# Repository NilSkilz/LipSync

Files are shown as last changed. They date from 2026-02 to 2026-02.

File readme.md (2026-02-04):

# LipSync

A rhythm-guided training system with haptic feedback. Turn oral service into a game they *really* don't want to lose.

Your sub follows a wave pattern on their phone while wearing an RF shock collar. Fall out of rhythm? They get a reminder. You control the pace.

Everything runs on a single ESP32 - no cloud, no apps to install, completely self-contained.

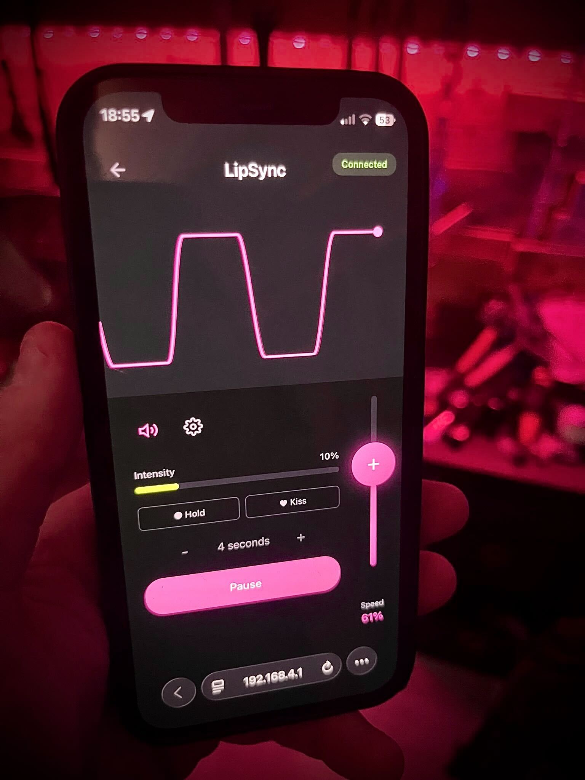
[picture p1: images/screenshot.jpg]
LipSync Screenshot


## Features

- **Visual guidance** - Smooth wave pattern shows the target rhythm
- **Audio cues** - High/low beeps signal direction changes
- **Adjustable pace** - Slide to control speed in real-time
- **Escalating feedback** - Starts gentle, increases with repeated mistakes
- **Shock collar integration** - Works with cheap 433MHz RF collars
- **Hold modes** - Special modes for deepthroat and kiss/lick
- **Motion tracking** - Optional IMU shows their actual movement vs target
- **No internet required** - Works completely offline
- **Mobile-first UI** - Designed for phones and tablets
- **Deep sleep** - Automatically sleeps after 1 minute of inactivity to save battery

## How It Works

```
┌──────────────────┐         ┌──────────────────────────────────┐
│   Phone/Tablet   │         │         ESP32 Device             │
│    (Browser)     │◄───────►│                                  │
│                  │  WiFi   │  - Web server (serves React app) │
│  Opens:          │         │  - WebSocket (real-time comms)   │
│  lipsync.local   │         │  - RF transmitter (collar ctrl)  │
│                  │         │  - MPU6050 IMU (motion tracking) │
└──────────────────┘         └──────────────────────────────────┘
```

The ESP32 creates its own WiFi network. Connect your phone, open the browser, and you're ready to play.

## Bill of Materials

| Component | Description | Qty | Approx. Price | Notes |
|---|---|-----|---|---|
| Seeed XIAO ESP32C3 | Compact ESP32-C3 board | 1 | $5-10 | Built-in LiPo charging |
| 3.7V LiPo Battery | 400-1000mAh | 1 | $5-10 | Connects to BAT+/BAT- pads |
| 433MHz RF Transmitter | FS1000A or similar | 1 | $2-5 | For collar control |
| RF Shock Collar | CaiXianlin protocol (common on Amazon/AliExpress) | 1 | $20-40 | The cheap ones with 3 channels |
| MPU6050 IMU | GY-521 module | 1 | $2-5 | Optional - for motion tracking |
| Tactile Button | 6x6mm momentary switch | 1 | $1 | Reset/wake button |
| LEDs | 3mm or 5mm, any color | 2 | $1 | Status indicators |
| Resistors | 220Ω (1/4W) | 2 | $1 | For LEDs |
| Enclosure | 3D printed or project box | 1 | $5 | Optional - STL files included |

**Total cost: ~$40-80** (depending on what you already have)

### Where to Buy

- **XIAO ESP32C3**: [Seeed Studio](https://www.seeedstudio.com/Seeed-XIAO-ESP32C3-p-5431.html), Amazon, AliExpress
- **RF Transmitter**: Search "433MHz transmitter module FS1000A"
- **Shock Collar**: Search "dog training collar 433MHz" - look for ones with vibrate/beep/shock modes
- **MPU6050**: Search "MPU6050 GY-521 module"
- **LiPo Battery**: Any 3.7V LiPo with JST connector (400-1000mAh recommended)

## Wiring

```
XIAO Pin      Component
──────────    ─────────
D10 (GPIO10)  RF Transmitter DATA
D4 (GPIO6)    MPU6050 SDA (optional)
D5 (GPIO7)    MPU6050 SCL (optional)
D0 (GPIO2)    Green LED → 220Ω → GND (connection status)
D3 (GPIO5)    Red LED → 220Ω → GND (session status)
D1 (GPIO3)    Button → GND (reset/wake, hold 1s)
3.3V          RF Transmitter VCC, MPU6050 VCC
GND           RF Transmitter GND, MPU6050 GND
BAT+/BAT-     3.7V LiPo battery
```

**Note**: RF range is reduced at 3.3V but sufficient for close range use. The XIAO charges the LiPo via USB-C.

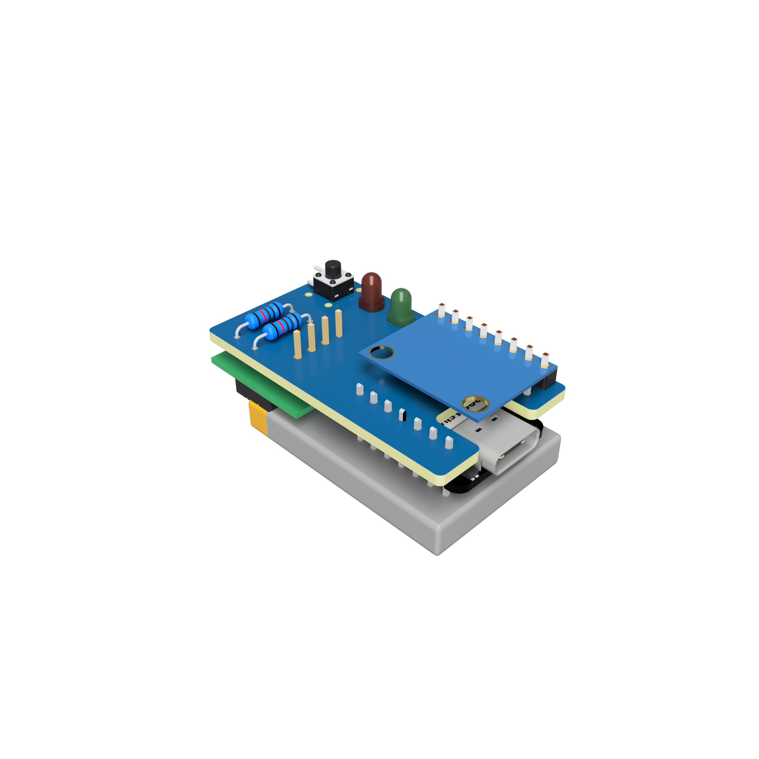
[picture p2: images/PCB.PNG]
LipSync PCB

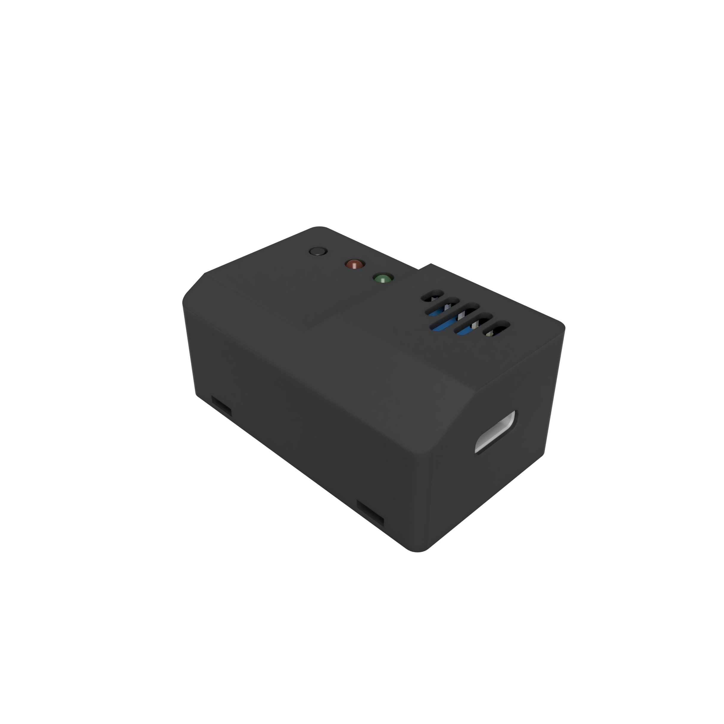
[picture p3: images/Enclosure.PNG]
LipSync Enclosure


## Quick Start

### 1. Flash the Firmware

```bash
# Install PlatformIO
brew install platformio   # macOS
# or: pip install platformio

# Clone and build
git clone https://github.com/yourusername/lipsync.git
cd lipsync/client
npm install
npm run build
cp -r dist/* ../firmware/data/

# Upload to XIAO ESP32C3
cd ../firmware
pio run -t upload -e seeed_xiao_esp32c3      # Upload firmware
pio run -t uploadfs -e seeed_xiao_esp32c3    # Upload web files
pio device monitor -b 115200                  # Monitor serial output
```

### 2. Connect and Play

1. Power on the ESP32
2. Connect to the "LipSync" WiFi network (password: `lipsync123`)
3. Open `http://lipsync.local` in your browser (or `http://192.168.4.1`)
4. Tap "Play" to begin!

### 3. Pairing the collar

Collars can be put into pairing mode by pressing the power button for ~2 seconds. There will be a beep, and the light will flash continuously.
To pair, send a "beep" signal from the app (open the settings cog and click the "Beep" button)

## Usage

### Main Controls

- **Speed Slider** (right side) - Drag up/down to control pace
- **Start/Pause** - Begin or pause the session
- **Hold/Kiss** - Quick buttons for hold modes

### Settings (gear icon)

- **Punishment Mode**: Beep, Vibrate, or Shock
- **Max Intensity**: Limit for shock strength
- **Increasing Intensity**: Start low, escalate with mistakes

### How Feedback Works

1. **Grace period** after speed changes - time to adjust
2. **First mistake** at a given speed - warning vibration
3. **Repeated mistakes** - shock at current intensity
4. **Each punishment** - intensity increases (if enabled)
5. **Speed change** - resets warning, gives grace period

## Development

### Local Web Development

```bash
cd client
npm run dev    # Starts at http://localhost:5173
```

### Firmware Development

```bash
cd firmware
pio run -e seeed_xiao_esp32c3                 # Build
pio run -t upload -e seeed_xiao_esp32c3       # Upload firmware
pio run -t uploadfs -e seeed_xiao_esp32c3     # Upload web files
pio device monitor -b 115200                   # Serial monitor
```

### Serial Commands

Connect at 115200 baud for debugging:
- `v` - Test vibrate
- `b` - Test beep
- `s` - Show status
- `h` - Help

## Project Structure

```
lipsync/
├── client/                 # React web app (Vite + TypeScript)
│   ├── src/
│   │   ├── components/     # UI components
│   │   ├── context/        # State management
│   │   ├── hooks/          # useWebSocket, useAudio
│   │   └── styles/         # CSS
│   └── package.json
├── firmware/               # ESP32 firmware (PlatformIO)
│   ├── src/main.cpp        # Main firmware
│   ├── include/            # Headers (config, RF, IMU)
│   ├── data/               # Built web files (LittleFS)
│   └── platformio.ini
├── enclosure/              # 3D printable enclosure STLs
└── screenshots/
```

## Power Management

The device automatically enters deep sleep after 1 minute of inactivity (no connected client and no active session) to conserve battery. Press the button to wake it up - LEDs will blink 3 times on boot.

Activity that resets the idle timer:
- Button press
- WebSocket client connecting
- WebSocket messages received
- Motion detected (cycles)

## Troubleshooting

### Can't connect to WiFi
- Make sure you're connecting to "LipSync" network
- Password is `lipsync123`
- Try `http://192.168.4.1` if `.local` doesn't work

### Collar not responding
- Check RF transmitter wiring (DATA to D10/GPIO10)
- Use serial monitor to confirm signals are being sent
- Ensure collar is paired (see pairing instructions above)

### Upload fails
- Try a different USB cable (must be data, not charge-only)
- Close any serial monitors first
- Make sure you're using `-e seeed_xiao_esp32c3`

### Web app not loading
- Make sure filesystem was uploaded: `pio run -t uploadfs -e seeed_xiao_esp32c3`
- Check serial output for errors

## Safety

This project involves shock collars. Please:
- **Always have a safeword** and a way to immediately stop
- **Test intensity on yourself first** before using on a partner
- **Start at low intensity** and increase gradually
- **Never use on anyone with a heart condition** or pacemaker
- **Remove if any unusual reaction occurs**
- This is for **consensual adult play only**

## Contributing

PRs welcome! Some ideas for improvements:
- [ ] Bluetooth collar support
- [ ] Pattern presets (slow build, random, etc.)
- [ ] Multi-sub support
- [ ] Session statistics/scoring
- [ ] OTA firmware updates

## License

MIT License - do whatever you want with it.

## Acknowledgments

- Built with [PlatformIO](https://platformio.org/), [React](https://react.dev/), [Vite](https://vitejs.dev/)
- RF protocol reverse-engineered from CaiXianlin collar remotes
- Massive props to Openshock for their work with the RF collars
- Thanks to some random guy off reddit for the idea
- Inspired by too many late nights and questionable life choices

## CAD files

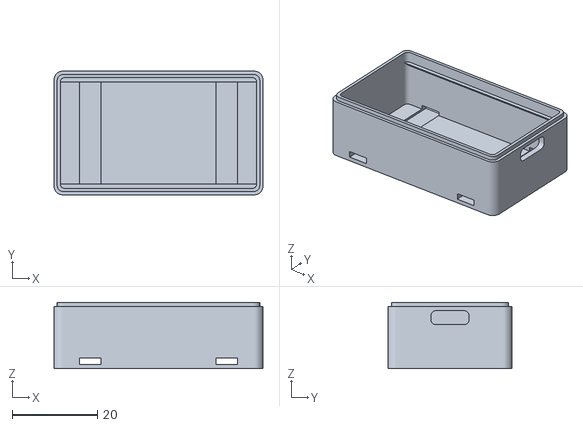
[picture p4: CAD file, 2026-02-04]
enclosure/Lower Body.stl
49.0 x 29.0 x 15.5

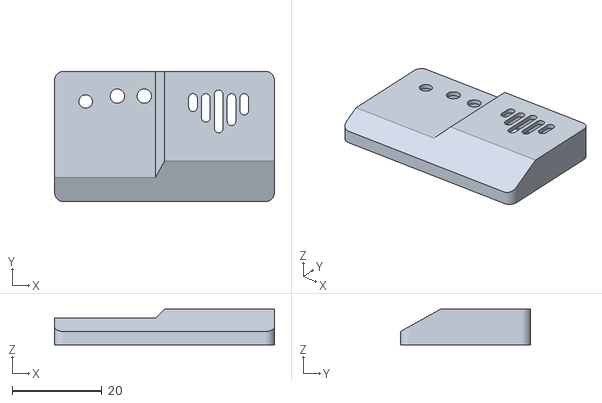
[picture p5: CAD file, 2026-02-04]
enclosure/Upper Body.stl
49.0 x 29.0 x 8.00

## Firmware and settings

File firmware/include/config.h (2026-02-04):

#pragma once

// ============================================
// PIN CONFIGURATION (XIAO ESP32C3)
// ============================================

// RF Transmitter pin (433MHz FS1000A)
#ifndef RF_TX_PIN
#define RF_TX_PIN 10  // D10
#endif

// IMU I2C pins (MPU6050/GY-521)
#ifndef IMU_SDA_PIN
#define IMU_SDA_PIN 6  // D4
#endif

#ifndef IMU_SCL_PIN
#define IMU_SCL_PIN 7  // D5
#endif

// Status LEDs
#ifndef LED_PIN
#define LED_PIN 2  // D0 - Green (connection status)
#endif

#ifndef LED2_PIN
#define LED2_PIN 5  // D3 - Red (session status)
#endif

// Button (active-low, uses internal pull-up)
#ifndef BUTTON_PIN
#define BUTTON_PIN 3  // D1
#endif

// ============================================
// WEBSOCKET SERVER CONFIGURATION
// ============================================

// mDNS hostname (device will be accessible at lipsync.local)
#define MDNS_HOSTNAME "lipsync"

// WebSocket server port
#define WS_PORT 80

// ============================================
// SHOCKER CONFIGURATION
// ============================================

// CaiXianlin protocol
#define SHOCKER_TRANSMITTER_ID 12345  // Change this! Must match your paired collar
#define SHOCKER_CHANNEL 0             // 0, 1, or 2

// ============================================
// MOTION DETECTION
// ============================================

// IMU sample rate (Hz)
#define IMU_SAMPLE_RATE 50

// Enable pitch streaming for visualization (comment out to disable)
// #define ENABLE_PITCH_STREAMING

// Minimum angle change to detect a peak (degrees)
#define PEAK_THRESHOLD 3.0

// Minimum cycle time (ms) - prevents noise
#define MIN_CYCLE_TIME 200

// Maximum cycle time (ms) - prevents stale readings
#define MAX_CYCLE_TIME 5000

// ============================================
// FEEDBACK DEFAULTS
// ============================================

#define DEFAULT_TARGET_BPM 60
#define DEFAULT_TARGET_DEPTH 30
#define DEFAULT_TOLERANCE 0.3
#define DEFAULT_INTENSITY 50

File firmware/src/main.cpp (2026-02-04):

#include <Arduino.h>
#include <WiFi.h>
#include <ESPmDNS.h>
#include <LittleFS.h>
#include <ESPAsyncWebServer.h>
#include <ArduinoJson.h>
#include "config.h"
#include "rf_transmitter.h"
#include "motion_tracker.h"
#include "esp_sleep.h"

// Components
RFTransmitter rf(RF_TX_PIN);
MotionTracker motion;
AsyncWebServer server(WS_PORT);
AsyncWebSocket ws("/ws");

// Hardware status
bool rfAvailable = false;
bool imuAvailable = false;

// Deep sleep
const unsigned long IDLE_SLEEP_TIMEOUT = 1 * 60 * 1000; // 1 minute idle timeout
unsigned long lastActivityTime = 0;

// Punishment modes
enum PunishmentMode { PUNISHMENT_OFF = 0, PUNISHMENT_BEEP = 1, PUNISHMENT_VIBRATE = 2, PUNISHMENT_SHOCK = 3 };

// Session modes (normal = motion tracking, others = hold positions)
enum SessionMode { MODE_NORMAL = 0, MODE_KISS_LICK = 1, MODE_DEEPTHROAT = 2 };

// Session state
struct SessionConfig {
    bool active = false;
    int targetBPM = DEFAULT_TARGET_BPM;
    int targetDepth = DEFAULT_TARGET_DEPTH;
    float tolerance = DEFAULT_TOLERANCE;
    int intensity = DEFAULT_INTENSITY;
    int maxIntensity = DEFAULT_INTENSITY;  // Maximum intensity cap
    bool increasingIntensity = true;       // Start low and increase
    int currentIntensity = 10;             // Current level (when increasing)
    uint16_t transmitterId = SHOCKER_TRANSMITTER_ID;
    uint8_t channel = SHOCKER_CHANNEL;
    int graceCycles = 0;  // Cycles to skip feedback after target change
    PunishmentMode punishmentMode = PUNISHMENT_VIBRATE;
    bool shockWarningGiven = false;  // For shock mode: one warning per speed
    SessionMode sessionMode = MODE_NORMAL;  // Current session mode
} session;

const int INTENSITY_START = 10;      // Starting intensity when increasing
const int INTENSITY_INCREMENT = 5;   // How much to increase each time

const int GRACE_PERIOD_CYCLES = 3;

// Connected client (we only support one at a time)
AsyncWebSocketClient* connectedClient = nullptr;

// Timing
unsigned long lastSample = 0;
unsigned long lastBlink = 0;
unsigned long lastCycleTime = 0;
unsigned long lastPitchBroadcast = 0;
unsigned long buttonPressStart = 0;
const unsigned long SAMPLE_INTERVAL = 1000 / IMU_SAMPLE_RATE;
const unsigned long BLINK_INTERVAL = 1000;
const unsigned long PITCH_BROADCAST_INTERVAL = 20;  // Send pitch every 20ms (50Hz, matches IMU)
const int STALL_CYCLE_COUNT = 3;  // Feedback after this many missed cycles
const unsigned long BUTTON_HOLD_TIME = 1000;  // Hold button 1 second to reset

// Forward declarations
void handleWebSocketMessage(void* arg, uint8_t* data, size_t len);
void onWsEvent(AsyncWebSocket* server, AsyncWebSocketClient* client, AwsEventType type, void* arg, uint8_t* data, size_t len);
void evaluateAndFeedback(const CycleEvent& cycle);
void broadcastState();
void sendToClient(const String& json);

// List directory recursively
void listDir(fs::FS &fs, const char* dirname, uint8_t levels) {
    Serial.printf("Listing directory: %s\n", dirname);
    File root = fs.open(dirname);
    if (!root || !root.isDirectory()) {
        Serial.println("  Failed to open directory");
        return;
    }
    File file = root.openNextFile();
    while (file) {
        if (file.isDirectory()) {
            Serial.printf("  DIR: %s\n", file.path());
            if (levels) {
                listDir(fs, file.path(), levels - 1);
            }
        } else {
            Serial.printf("  FILE: %s (%d bytes)\n", file.path(), file.size());
        }
        file = root.openNextFile();
    }
}

void enterDeepSleep() {
    Serial.println("Entering deep sleep...");

    // Turn off LEDs
    digitalWrite(LED_PIN, LOW);
    digitalWrite(LED2_PIN, LOW);

    // Stop services cleanly
    WiFi.mode(WIFI_OFF);
    btStop();

    // Wake on button press (D1 = GPIO3, active LOW)
    esp_deep_sleep_enable_gpio_wakeup(
        BIT(GPIO_NUM_3),
        ESP_GPIO_WAKEUP_GPIO_LOW
    );

    delay(100); // Let serial flush
    esp_deep_sleep_start();
}

void setup() {
    Serial.begin(115200);
    delay(1000);
    Serial.println("\n\n=== LipSync Firmware ===");

    esp_sleep_wakeup_cause_t wakeReason = esp_sleep_get_wakeup_cause();
    if (wakeReason == ESP_SLEEP_WAKEUP_GPIO) {
        Serial.println("Woke from deep sleep via button");
    } else {
        Serial.println("Normal boot");
    }

    // Status LEDs
    pinMode(LED_PIN, OUTPUT);   // LED1: Green - Connection status
    pinMode(LED2_PIN, OUTPUT);  // LED2: Red - Session status

    // Blink LEDs on boot to verify wiring
    Serial.println("LED test...");
    for (int i = 0; i < 3; i++) {
        digitalWrite(LED_PIN, HIGH);
        digitalWrite(LED2_PIN, HIGH);
        delay(150);
        digitalWrite(LED_PIN, LOW);
        digitalWrite(LED2_PIN, LOW);
        delay(150);
    }

    // Reset button (active-low with internal pull-up)
    pinMode(BUTTON_PIN, INPUT_PULLUP);

    // Initialize LittleFS
    if (!LittleFS.begin(true)) {
        Serial.println("LittleFS mount failed!");
    } else {
        Serial.println("LittleFS mounted");
        // List all files recursively
        listDir(LittleFS, "/", 3);
    }

    // Initialize RF transmitter (optional)
    rfAvailable = rf.begin();
    if (!rfAvailable) {
        Serial.println("RF init failed - continuing without RF");
    }

    // Initialize motion tracker (optional)
    imuAvailable = motion.begin();
    if (!imuAvailable) {
        Serial.println("IMU init failed - continuing without IMU");
    }

    // Start Access Point
    WiFi.mode(WIFI_AP);
    const char* apSSID = "LipSync";
    const char* apPassword = "lipsync123";  // Min 8 characters
    WiFi.softAP(apSSID, apPassword);
    Serial.printf("Access Point started: %s (password: %s)\n", apSSID, apPassword);
    Serial.printf("AP IP Address: %s\n", WiFi.softAPIP().toString().c_str());

    // Start mDNS
    if (MDNS.begin(MDNS_HOSTNAME)) {
        Serial.printf("mDNS started: http://%s.local\n", MDNS_HOSTNAME);
        MDNS.addService("http", "tcp", WS_PORT);
    } else {
        Serial.println("mDNS failed to start");
    }

    // Setup WebSocket handler
    ws.onEvent(onWsEvent);
    server.addHandler(&ws);

    // Serve static files from LittleFS with correct MIME types
    server.on("/assets/index.js", HTTP_GET, [](AsyncWebServerRequest* request) {
        Serial.println("Request for /assets/index.js");
        if (LittleFS.exists("/assets/index.js")) {
            Serial.println("  File exists!");
            request->send(LittleFS, "/assets/index.js", "application/javascript");
        } else {
            Serial.println("  File NOT found!");
            request->send(404, "text/plain", "File not found");
        }
    });
    server.on("/assets/index.css", HTTP_GET, [](AsyncWebServerRequest* request) {
        Serial.println("Request for /assets/index.css");
        if (LittleFS.exists("/assets/index.css")) {
            Serial.println("  File exists!");
            request->send(LittleFS, "/assets/index.css", "text/css");
        } else {
            Serial.println("  File NOT found!");
            request->send(404, "text/plain", "File not found");
        }
    });
    server.on("/assets/audio/kiss-lick.mp3", HTTP_GET, [](AsyncWebServerRequest* request) {
        Serial.println("Request for /assets/audio/kiss-lick.mp3");
        if (LittleFS.exists("/assets/audio/kiss-lick.mp3")) {
            Serial.println("  File exists!");
            request->send(LittleFS, "/assets/audio/kiss-lick.mp3", "audio/mpeg");
        } else {
            Serial.println("  File NOT found!");
            request->send(404, "text/plain", "File not found");
        }
    });

    // Serve other static files
    server.serveStatic("/", LittleFS, "/").setDefaultFile("index.html");

    // Handle 404 - serve index.html for SPA routing
    server.onNotFound([](AsyncWebServerRequest* request) {
        Serial.printf("404: %s\n", request->url().c_str());
        if (LittleFS.exists("/index.html")) {
            request->send(LittleFS, "/index.html", "text/html");
        } else {
            request->send(404, "text/plain", "Not found - upload filesystem first");
        }
    });

    // Start server
    server.begin();
    Serial.printf("Web server started on port %d\n", WS_PORT);

    digitalWrite(LED_PIN, LOW);
    Serial.println("Setup complete!");
    Serial.printf("Open: http://%s.local or http://%s\n",
                  MDNS_HOSTNAME,
                  WiFi.softAPIP().toString().c_str());
    lastActivityTime = millis();
}

void loop() {
    unsigned long now = millis();
    // Check reset button (hold for 1 second to reset)
    if (digitalRead(BUTTON_PIN) == LOW) {
        lastActivityTime = now;
        if (buttonPressStart == 0) {
            buttonPressStart = millis();
            Serial.println("Button pressed - hold 1s to reset");
        } else if (millis() - buttonPressStart >= BUTTON_HOLD_TIME) {
            Serial.println("Resetting...");
            delay(100);
            ESP.restart();
        }
    } else {
        buttonPressStart = 0;
    }

    // LED1: Blink - fast when client connected, slow when waiting
    unsigned long blinkRate = connectedClient ? 200 : 1000;
    if (millis() - lastBlink >= blinkRate) {
        lastBlink = millis();
        digitalWrite(LED_PIN, !digitalRead(LED_PIN));
    }

    // LED2: Solid when session active
    digitalWrite(LED2_PIN, session.active ? HIGH : LOW);

    // Handle serial commands for testing
    if (Serial.available()) {
        String cmd = Serial.readStringUntil('\n');
        cmd.trim();
        if (cmd == "v" || cmd == "vibrate") {
            Serial.println("Vibrate command (50%)");
            if (rfAvailable) {
                rf.vibrate(session.transmitterId, session.channel, 50);
            } else {
                Serial.println("(RF not available)");
            }
        } else if (cmd == "b" || cmd == "beep") {
            Serial.println("Beep command");
            if (rfAvailable) {
                rf.beep(session.transmitterId, session.channel);
            } else {
                Serial.println("(RF not available)");
            }
        } else if (cmd == "s" || cmd == "status") {
            Serial.printf("RF: %s, IMU: %s, Client: %s\n",
                rfAvailable ? "OK" : "NO",
                imuAvailable ? "OK" : "NO",
                connectedClient ? "CONNECTED" : "NONE");
            Serial.printf("IP: %s\n", WiFi.localIP().toString().c_str());
            Serial.printf("Transmitter ID: %d, Channel: %d\n", session.transmitterId, session.channel);
        } else if (cmd == "r" || cmd == "reset") {
            Serial.println("Resetting...");
            delay(100);
            ESP.restart();
        } else if (cmd == "h" || cmd == "help") {
            Serial.println("Commands: v=vibrate, b=beep, s=status, r=reset, h=help");
        } else if (cmd.length() > 0) {
            Serial.println("Unknown command. Type 'h' for help.");
        }
    }

    // Clean up disconnected WebSocket clients
    ws.cleanupClients();

    // Sample IMU at fixed rate (only if available)
    if (imuAvailable && millis() - lastSample >= SAMPLE_INTERVAL) {
        lastSample = millis();

        motion.update();

        // Check for completed cycle
        if (motion.hasCycle()) {
            lastActivityTime = now;
            CycleEvent cycle = motion.getCycle();
            lastCycleTime = millis();

            if (session.active) {
                evaluateAndFeedback(cycle);
            }

            // Send cycle data to client
            if (connectedClient) {
                JsonDocument doc;
                doc["type"] = "cycle";
                doc["data"]["duration"] = cycle.duration;
                doc["data"]["depth"] = cycle.depth;
                doc["data"]["timestamp"] = cycle.timestamp;

                String json;
                serializeJson(doc, json);
                sendToClient(json);
            }
        }

        #ifdef ENABLE_PITCH_STREAMING
        // Broadcast pitch at throttled rate for visualization (25Hz)
        if (connectedClient && millis() - lastPitchBroadcast >= 40) {
            lastPitchBroadcast = millis();
            JsonDocument doc;
            doc["type"] = "pitch";
            doc["data"]["pitch"] = motion.getPitch();
            String json;
            serializeJson(doc, json);
            sendToClient(json);
        }
        #endif

        // Check for stall (no motion for too long) - only in normal mode
        if (session.active && session.sessionMode == MODE_NORMAL && session.graceCycles == 0 && lastCycleTime > 0) {
            unsigned long expectedCycleTime = 60000 / session.targetBPM;
            unsigned long stallTimeout = expectedCycleTime * STALL_CYCLE_COUNT;
            unsigned long timeSinceLastCycle = millis() - lastCycleTime;

            if (timeSinceLastCycle > stallTimeout && session.punishmentMode != PUNISHMENT_OFF) {
                Serial.printf("STALL detected: no motion for %lums (timeout: %lums)\n",
                              timeSinceLastCycle, stallTimeout);

                // Calculate feedback intensity
                int feedbackIntensity;
                if (session.increasingIntensity) {
                    feedbackIntensity = session.currentIntensity;
                } else {
                    feedbackIntensity = session.maxIntensity;
                }

                const char* punishmentType = "none";
                bool isWarning = false;

                if (rfAvailable) {
                    switch (session.punishmentMode) {
                        case PUNISHMENT_BEEP:
                            rf.beep(session.transmitterId, session.channel);
                            punishmentType = "beep";
                            break;
                        case PUNISHMENT_VIBRATE:
                            rf.vibrate(session.transmitterId, session.channel, feedbackIntensity);
                            punishmentType = "vibrate";
                            break;
                        case PUNISHMENT_SHOCK:
                            // One warning per speed, then shock
                            if (!session.shockWarningGiven) {
                                rf.vibrate(session.transmitterId, session.channel, feedbackIntensity);
                                punishmentType = "vibrate";
                                isWarning = true;
                                session.shockWarningGiven = true;
                                // Grace period after warning to correct
                                session.graceCycles = GRACE_PERIOD_CYCLES;
                            } else {
                                rf.shock(session.transmitterId, session.channel, feedbackIntensity);
                                punishmentType = "shock";
                                // Grace period after shock to recover
                                session.graceCycles = GRACE_PERIOD_CYCLES;
                            }
                            break;
                        default:
                            break;
                    }
                }

                // Increase intensity for next time (if enabled), but not for warnings
                if (session.increasingIntensity && !isWarning) {
                    session.currentIntensity = min(session.currentIntensity + INTENSITY_INCREMENT, session.maxIntensity);
                    Serial.printf("Next intensity: %d%% (max: %d%%)\n", session.currentIntensity, session.maxIntensity);
                }

                // Reset timer to avoid continuous feedback
                lastCycleTime = millis();

                // Notify client
                if (connectedClient) {
                    JsonDocument doc;
                    doc["type"] = "punishment";
                    doc["data"]["punishmentType"] = punishmentType;
                    doc["data"]["intensity"] = feedbackIntensity;
                    doc["data"]["isWarning"] = isWarning;
                    doc["data"]["reason"] = "stall";
                    String json;
                    serializeJson(doc, json);
                    sendToClient(json);
                }
            }
        }
    }
    if (!session.active &&
        !connectedClient &&
        (now - lastActivityTime > IDLE_SLEEP_TIMEOUT)) {

        Serial.println("Idle timeout reached");
        delay(200);
        enterDeepSleep();
    }
}

void onWsEvent(AsyncWebSocket* server, AsyncWebSocketClient* client, AwsEventType type, void* arg, uint8_t* data, size_t len) {
    switch (type) {
        case WS_EVT_CONNECT:
            lastActivityTime = millis();
            Serial.printf("WebSocket client #%u connected from %s\n", client->id(), client->remoteIP().toString().c_str());
            connectedClient = client;
            broadcastState();
            break;

        case WS_EVT_DISCONNECT:
            Serial.printf("WebSocket client #%u disconnected\n", client->id());
            if (connectedClient == client) {
                connectedClient = nullptr;
                session.active = false;  // Safety: stop session on disconnect
            }
            break;

        case WS_EVT_DATA:
            lastActivityTime = millis();
            handleWebSocketMessage(arg, data, len);
            break;

        case WS_EVT_PONG:
        case WS_EVT_ERROR:
            break;
    }
}
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

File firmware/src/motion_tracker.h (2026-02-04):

#pragma once

#include <Arduino.h>
#include <Wire.h>
#include <MPU6050.h>
#include "config.h"

struct CycleEvent {
    unsigned long duration;  // ms
    float depth;            // degrees
    unsigned long timestamp;
};

class MotionTracker {
public:
    MotionTracker();
    bool begin();
    void update();
    
    // Check if a new cycle was completed
    bool hasCycle();
    CycleEvent getCycle();
    
    // Current readings
    float getPitch() { return _pitch; }
    float getRoll() { return _roll; }
    
private:
    MPU6050 _mpu;
    
    // Current orientation
    float _pitch = 0;
    float _roll = 0;
    
    // Complementary filter state
    float _accelPitch = 0;
    float _gyroPitch = 0;
    unsigned long _lastUpdate = 0;
    
    // Cycle detection
    float _lastPitch = 0;
    float _prevPitch = 0;
    bool _wasIncreasing = false;
    unsigned long _lastPeakTime = 0;
    float _minPitch = 0;
    float _maxPitch = 0;
    
    // Completed cycle storage
    bool _cycleReady = false;
    CycleEvent _lastCycle;
    
    void calculateOrientation(int16_t ax, int16_t ay, int16_t az,
                              int16_t gx, int16_t gy, int16_t gz);
    bool detectPeak();
};

// Implementation

MotionTracker::MotionTracker() {}

bool MotionTracker::begin() {
    Serial.printf("IMU: Initializing on SDA=%d, SCL=%d\n", IMU_SDA_PIN, IMU_SCL_PIN);
    Wire.begin(IMU_SDA_PIN, IMU_SCL_PIN);

    // Scan for I2C devices
    Serial.println("IMU: Scanning I2C bus...");
    for (uint8_t addr = 1; addr < 127; addr++) {
        Wire.beginTransmission(addr);
        if (Wire.endTransmission() == 0) {
            Serial.printf("IMU: Found device at 0x%02X\n", addr);
        }
    }

    _mpu.initialize();
    delay(100);  // Give chip time to wake up

    // Read WHO_AM_I register to see what chip reports
    uint8_t whoami = _mpu.getDeviceID();
    Serial.printf("IMU: WHO_AM_I = 0x%02X\n", whoami);

    if (!_mpu.testConnection()) {
        // testConnection() expects WHO_AM_I == 0x34 (which is 0x68 >> 1)
        // Some clones report different values - proceed anyway since I2C scan found it
        Serial.println("IMU: testConnection failed but device found - proceeding anyway");
    }
    
    // Configure MPU6050
    _mpu.setFullScaleGyroRange(MPU6050_GYRO_FS_500);  // ±500°/s
    _mpu.setFullScaleAccelRange(MPU6050_ACCEL_FS_4);  // ±4g
    _mpu.setDLPFMode(MPU6050_DLPF_BW_42);  // Low pass filter
    
    _lastUpdate = millis();
    Serial.println("Motion Tracker initialized");
    return true;
}

void MotionTracker::calculateOrientation(int16_t ax, int16_t ay, int16_t az,
                                         int16_t gx, int16_t gy, int16_t gz) {
    unsigned long now = millis();
    float dt = (now - _lastUpdate) / 1000.0f;
    _lastUpdate = now;
    
    // Convert raw values
    float accelX = ax / 8192.0f;  // ±4g scale
    float accelY = ay / 8192.0f;
    float accelZ = az / 8192.0f;
    float gyroX = gx / 65.5f;     // ±500°/s scale
    
    // Calculate pitch from accelerometer
    _accelPitch = atan2(accelX, sqrt(accelY * accelY + accelZ * accelZ)) * 180.0f / PI;
    
    // Integrate gyroscope
    _gyroPitch = _pitch + gyroX * dt;
    
    // Complementary filter (98% gyro, 2% accel)
    _pitch = 0.98f * _gyroPitch + 0.02f * _accelPitch;
    
    // Calculate roll (for debugging/display)
    _roll = atan2(accelY, accelZ) * 180.0f / PI;
}

bool MotionTracker::detectPeak() {
    bool isIncreasing = _pitch > _lastPitch;
    bool directionChanged = (_wasIncreasing && !isIncreasing) || (!_wasIncreasing && isIncreasing);

    _prevPitch = _lastPitch;
    _lastPitch = _pitch;
    _wasIncreasing = isIncreasing;

    // Check if we've traveled enough since last peak (use accumulated range, not instantaneous movement)
    float range = _maxPitch - _minPitch;

    return directionChanged && range > PEAK_THRESHOLD;
}

void MotionTracker::update() {
    int16_t ax, ay, az, gx, gy, gz;
    _mpu.getMotion6(&ax, &ay, &az, &gx, &gy, &gz);

    calculateOrientation(ax, ay, az, gx, gy, gz);

    // Track min/max for depth
    _minPitch = min(_minPitch, _pitch);
    _maxPitch = max(_maxPitch, _pitch);
    
    // Check for peak (direction change = one motion complete)
    if (detectPeak()) {
        unsigned long now = millis();
        unsigned long motionTime = now - _lastPeakTime;
        float depth = _maxPitch - _minPitch;
        const char* direction = _wasIncreasing ? "DOWN" : "UP";  // Just changed, so opposite

        // Valid motion?
        if (motionTime >= MIN_CYCLE_TIME && motionTime <= MAX_CYCLE_TIME && _lastPeakTime > 0) {
            _lastCycle.duration = motionTime * 2;  // Full cycle = 2 motions
            _lastCycle.depth = depth;
            _lastCycle.timestamp = now;
            _cycleReady = true;

            float bpm = 30000.0f / motionTime;  // 60000 / (motionTime * 2)
            Serial.printf(">>> %s motion: %3.0f BPM | depth=%4.1f° | %lums\n",
                          direction, bpm, depth, motionTime);
        } else if (_lastPeakTime > 0) {
            Serial.printf(">>> %s motion rejected: %lums (need %d-%dms)\n",
                          direction, motionTime, MIN_CYCLE_TIME, MAX_CYCLE_TIME);
        }

        // Reset for next motion
        _lastPeakTime = now;
        _minPitch = _pitch;
        _maxPitch = _pitch;
    }
}

bool MotionTracker::hasCycle() {
    return _cycleReady;
}

CycleEvent MotionTracker::getCycle() {
    _cycleReady = false;
    return _lastCycle;
}

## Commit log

2025-12-12 Added enclosure
    [base.stl]
2025-12-12 Updated base
    [base.stl]
2025-12-12 Added headband adapter
    [headband_adapter.scad]
2025-12-22 Lots of changes!
    [enclosure.scad, enclosure2.scad, headband_adapter.scad]
2026-02-04 Added images and enclosure files
    [Lower Body.stl, Upper Body.stl]
